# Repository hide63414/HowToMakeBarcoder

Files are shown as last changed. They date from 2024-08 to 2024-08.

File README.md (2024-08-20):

# Barcoderの作り方
## 概要
バーコードリーダーをバーコーダーに改造する方法 [バーコーダー](https://www.electronicosfantasticos.com/works/barcoder/)<br>

## 部品
* バーコードリーダー　[BEVA バーコードリーダー](https://www.amazon.co.jp/BEVA-%E3%83%90%E3%83%BC%E3%82%B3%E3%83%BC%E3%83%89%E3%83%AA%E3%83%BC%E3%83%80%E3%83%BC-%E3%83%90%E3%83%BC%E3%82%B3%E3%83%BC%E3%83%89%E3%82%B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)<br>
他の機種でも可　例えば [Tera バーコードリーダー](https://www.amazon.co.jp/gp/product/B081W1VBHJ/ref=ppx_yo_dt_b_asin_title_o08_s00?ie=UTF8&th=1)<br>
⇒レーザー光学式（ミラーでスキャンするタイプ）で、走査速度が25Hz程度の低速のもの　

* アンプ　[HT82V73A](https://akizukidenshi.com/catalog/g/gI-17849/)
* スピーカー [マイクロスピーカー](https://akizukidenshi.com/catalog/g/gP-12494/)
* コンデンサ　[0.1μF](https://akizukidenshi.com/catalog/g/gP-17818/)  
* コンデンサ　[1.0μF](https://akizukidenshi.com/catalog/g/gP-07549/)
* オーディオ延長ケーブル　[3.5mmステレオミニ](https://akizukidenshi.com/catalog/g/gC-13084/)
* スライドスイッチ　[スライドスイッチ](https://akizukidenshi.com/catalog/g/gP-15370/)
* スペーサ [樹脂ワッシャー](https://akizukidenshi.com/catalog/g/g115881/)
* バーコーダ用基板<br>
  <details><summary>基板</summary>
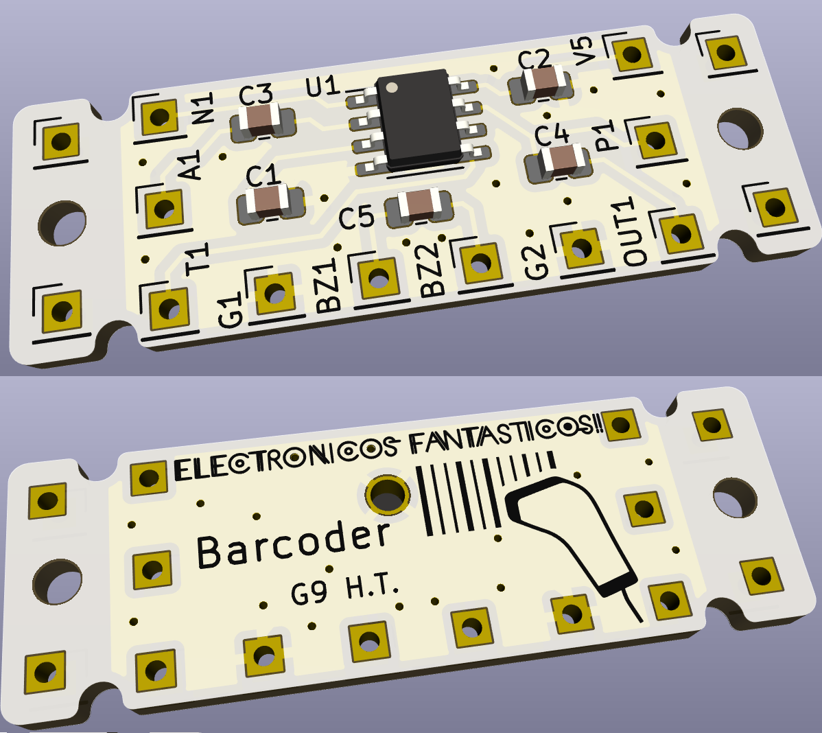
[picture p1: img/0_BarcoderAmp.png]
  </details>

  あるいは
  
  アンプ実装済み基板 [HT82V739使用アンプ基板](https://akizukidenshi.com/catalog/g/g103234/)<br>
  (上記基板使用の際はアンプとコンデンサは不要、配線方法は回路図を参考にしてください。）

## 回路図
<details><summary>回路図</summary>
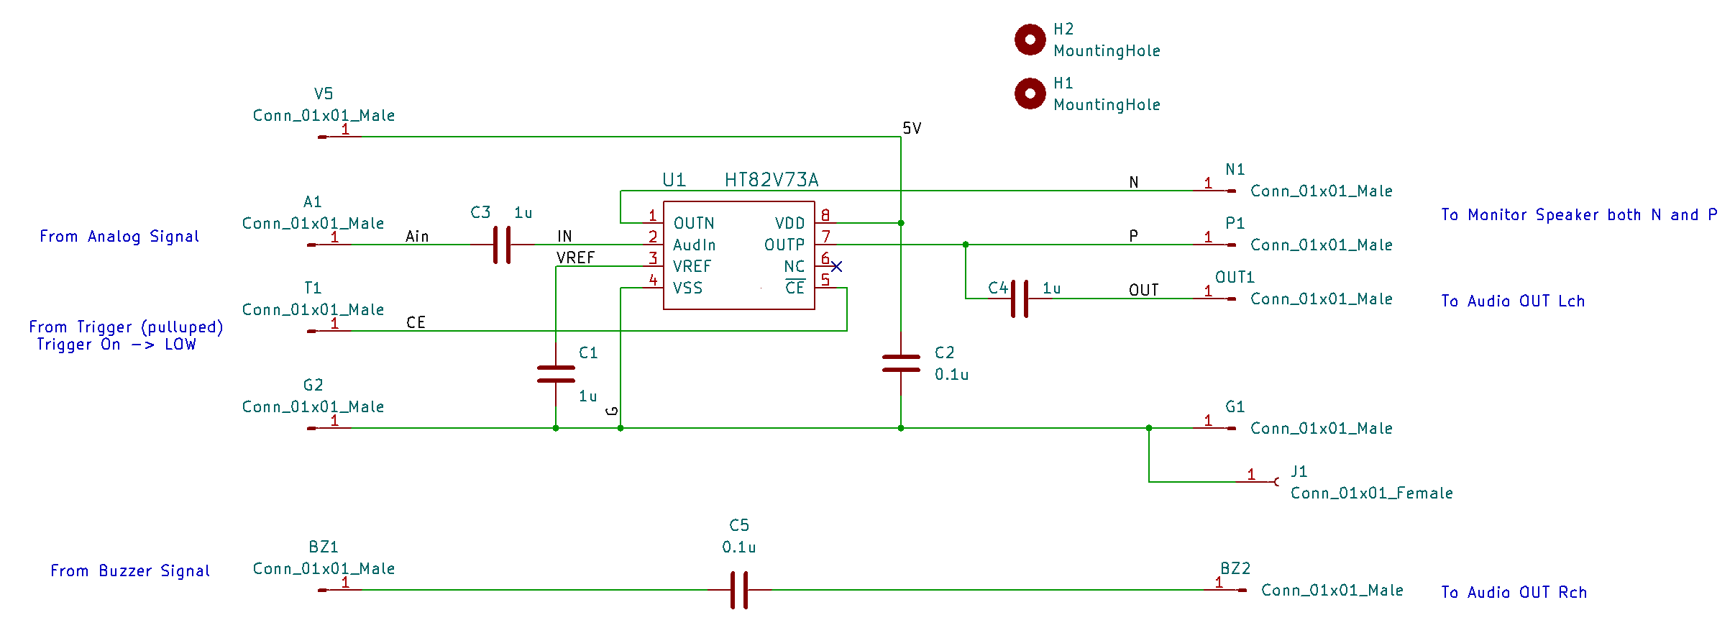
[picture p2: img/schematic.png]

</details>

## 作製手順
0. バーコードリーダーの動作設定
常にレーザーが照射される連続動作モード(Continuous Mode)にするため、設定用のバーコードを読み込む。

1. 配線の準備<br>
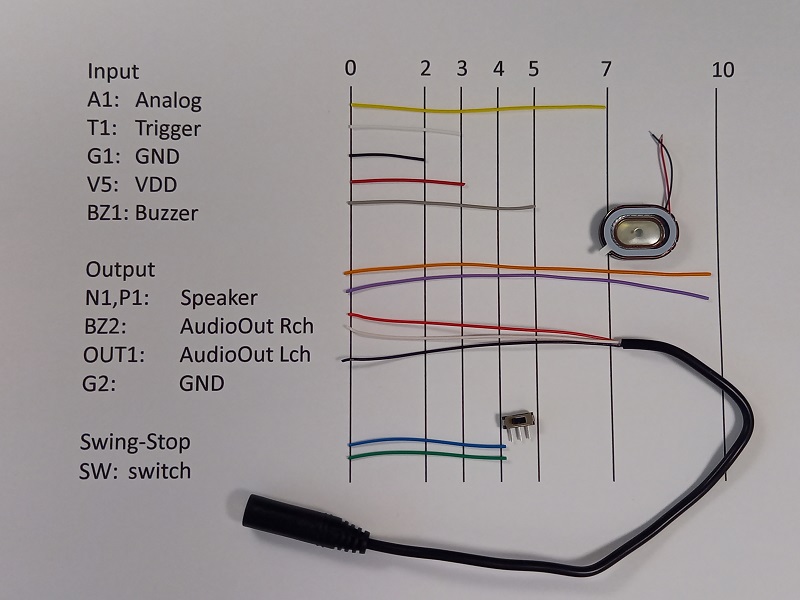
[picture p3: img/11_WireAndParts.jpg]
<br>

1. バーコードリーダ分解<br>
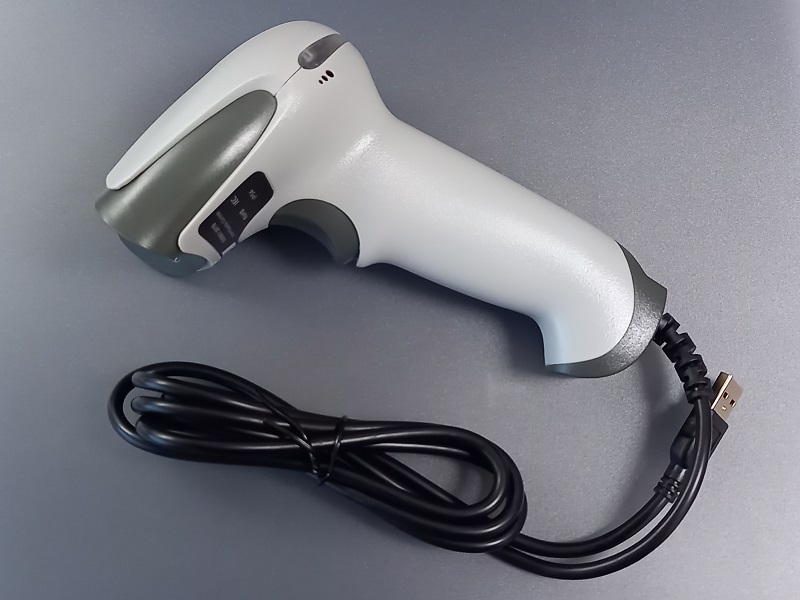
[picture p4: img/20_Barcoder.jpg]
<br>
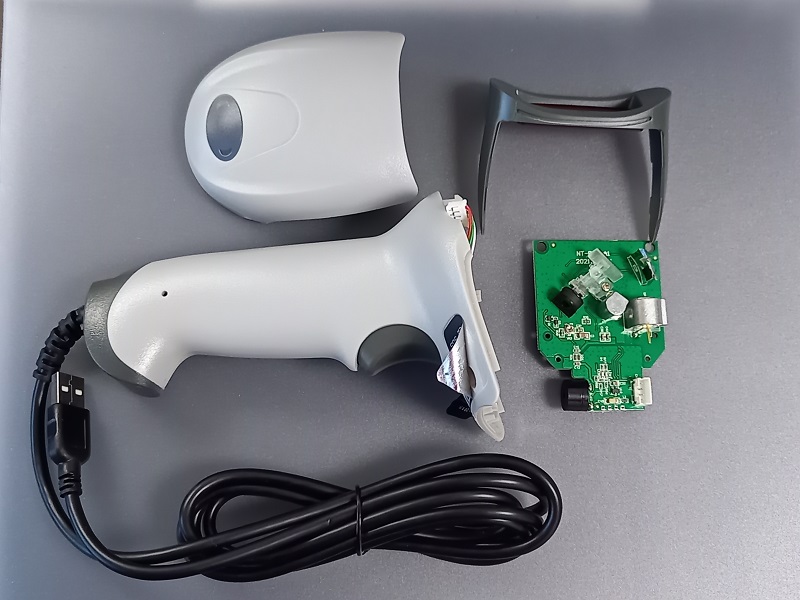
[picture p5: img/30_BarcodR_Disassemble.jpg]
<br>

1. 配線接続<br>
基板裏側シールドを外す<br>
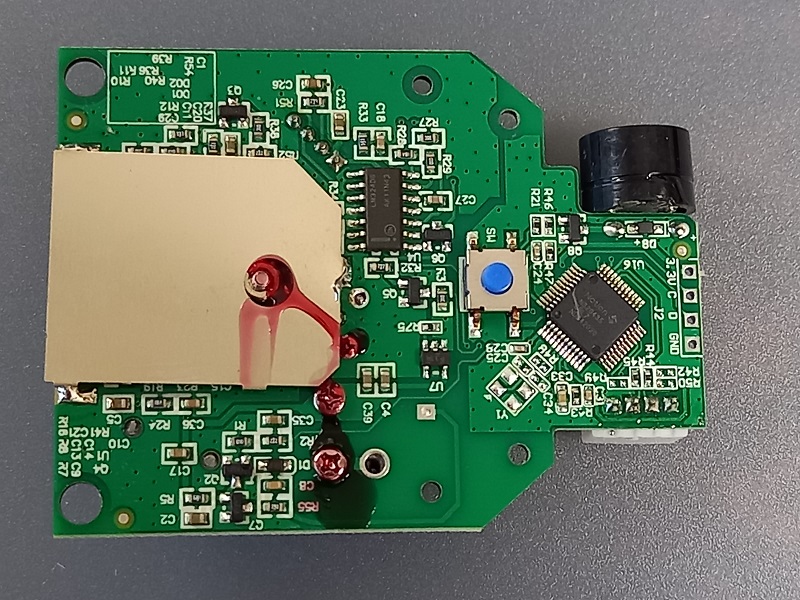
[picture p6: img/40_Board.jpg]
<br>
アナログ(黄)、トリガ(白)、ブザー(灰)、スイング(青・緑)を接続<br>
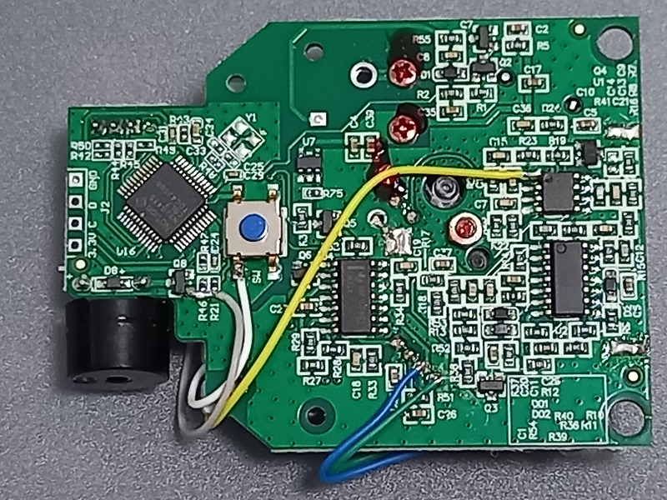
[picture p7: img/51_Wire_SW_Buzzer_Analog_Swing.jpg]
<br>
アナログ(黄) 8pinICの1番ピン<br>
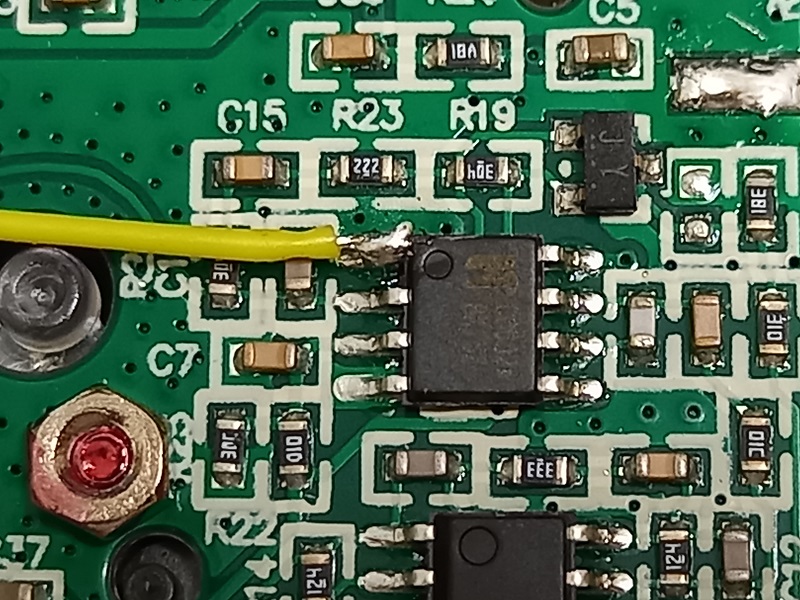
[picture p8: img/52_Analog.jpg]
<br>
トリガ(白)Q8,R46,R21、ブザー(灰)スイッチ足<br>
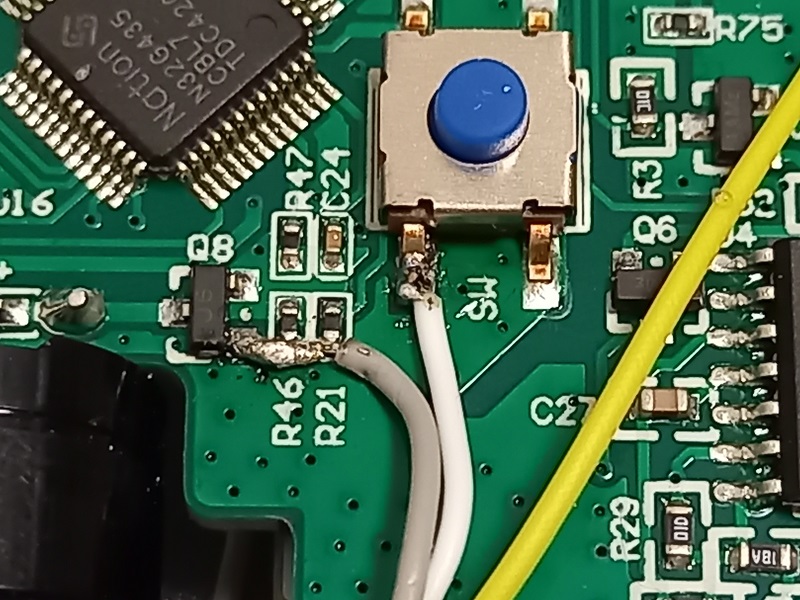
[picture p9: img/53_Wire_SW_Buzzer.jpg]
<br>
スイング(青・緑) コイル端子4本のうち外側2本<br>
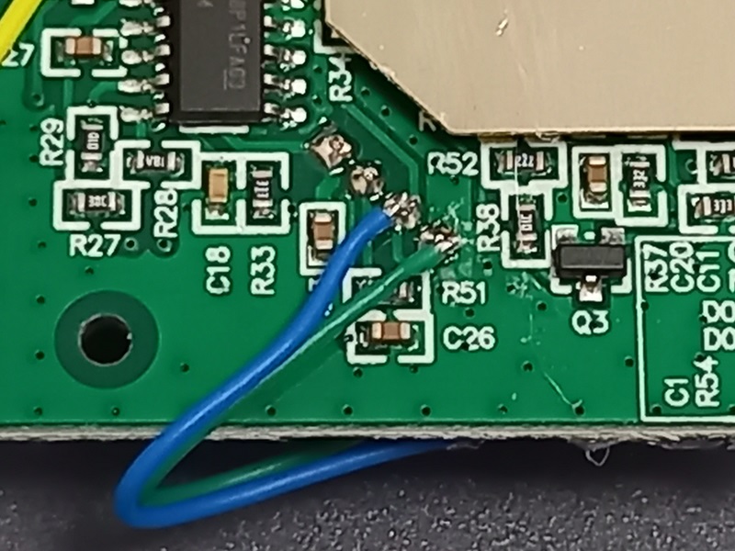
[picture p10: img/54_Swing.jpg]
<br> 

1. 筐体穴あけ(Φ3.2)<br>
AudioOUT用(筐体内に貫通する位置注意)、スピーカー用<br>
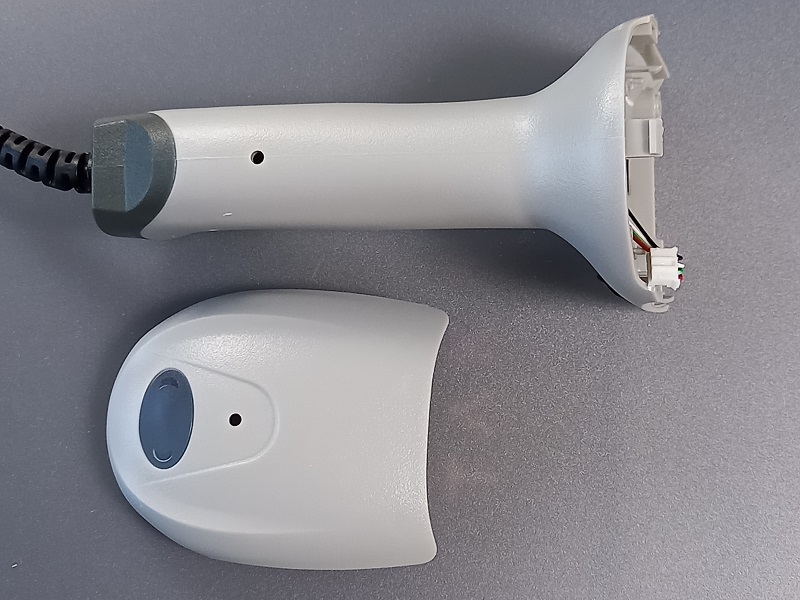
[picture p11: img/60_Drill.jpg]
<br>

1. スピーカ取り付け<br>
スピーカーに配線(橙、紫)取り付け、両面テープで貼る<br>
ホットメルトで固定<br>
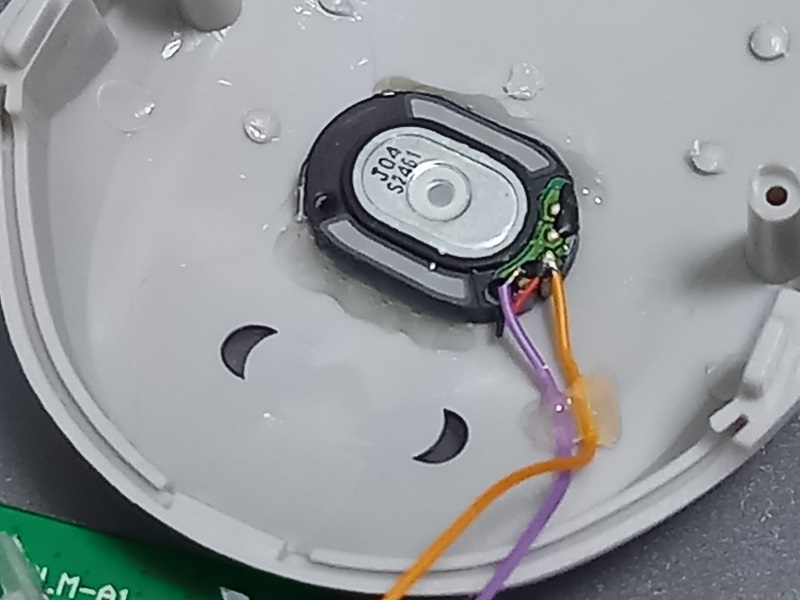
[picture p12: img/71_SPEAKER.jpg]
<br>

1. 基板に部品実装<br>
AMP,C1,C3,C4,C5<br>
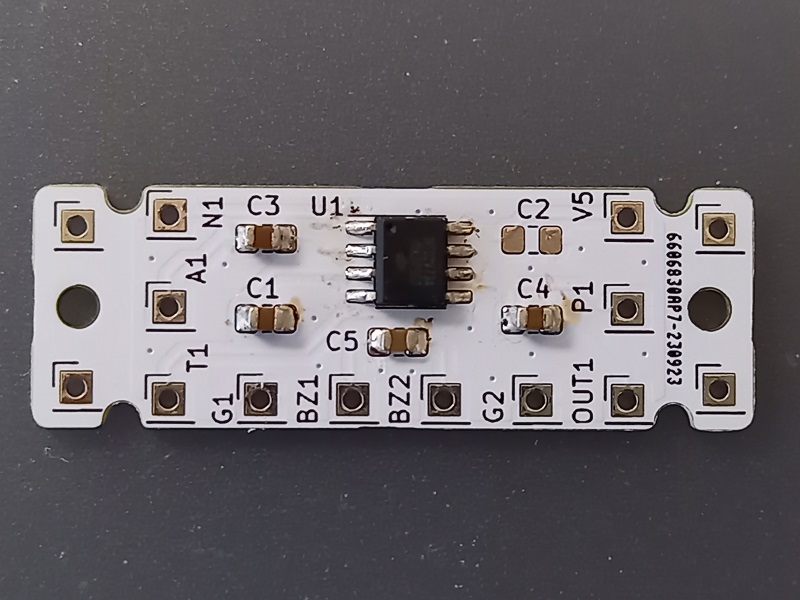
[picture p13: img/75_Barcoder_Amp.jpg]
 <br>

1. 基板に配線接続<br>
GND(黒)G2、5V(赤)V5<br>
アナログ(黄)A1、トリガ(白)T1、ブザー(灰)BZ1<br>
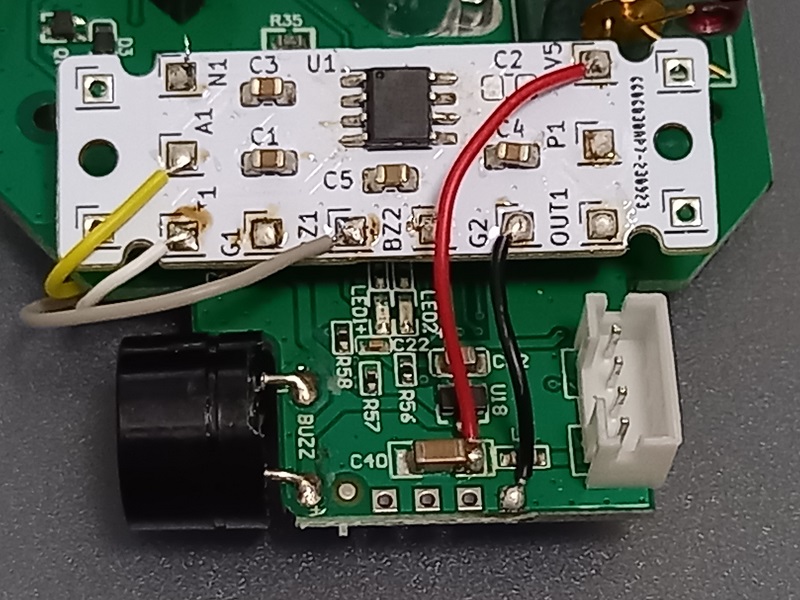
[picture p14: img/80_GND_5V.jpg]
<br>

1. スイング停止用スイッチ取り付け<br>
スイングするミラーに当たらない位置にホットボンドで固定する。<br>
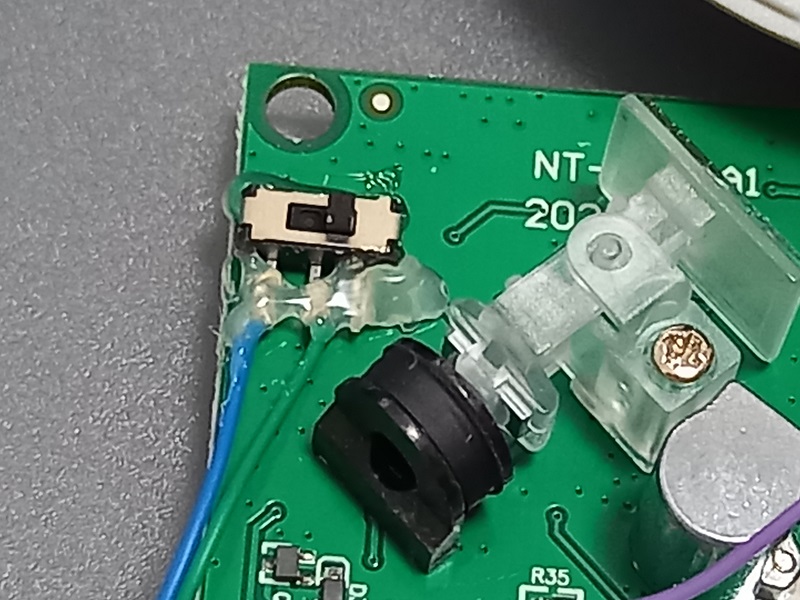
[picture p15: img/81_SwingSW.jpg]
<br>
スイング停止する場合は、スイッチを短絡側に切り替え<br>
ミラーをテープで固定する<br>
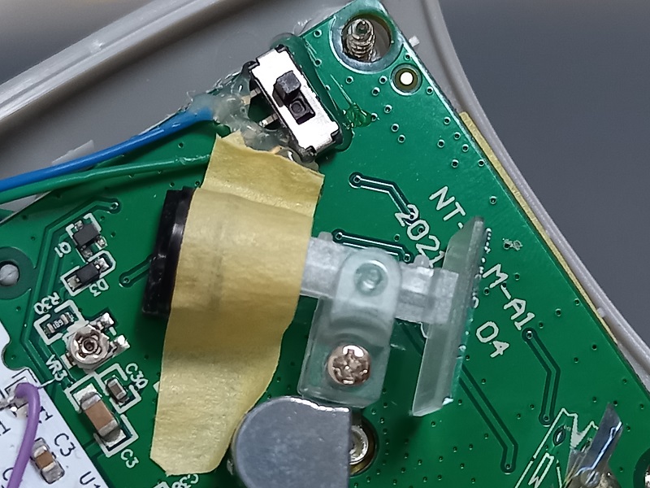
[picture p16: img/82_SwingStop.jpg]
<br>

1. 動作確認<br>
スピーカー(橙、紫)　P1,N1 どちらでもいい<br>
USBコネクタを取り付け<br>
基板反対面のスイッチを押して、ブザーから音が出ればOK<br>
音がでない場合は接続、基板上のICのはんだ付け状況を確認<br>
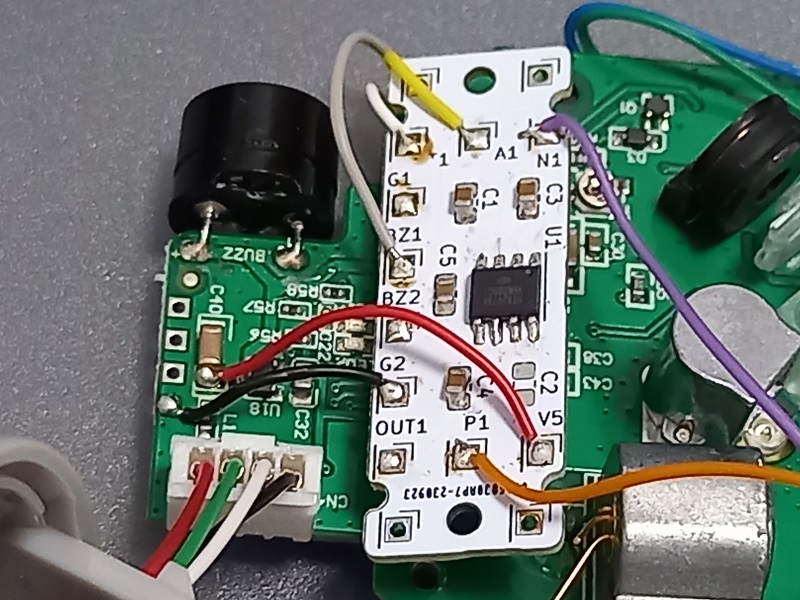
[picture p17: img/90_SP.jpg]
<br>

1. AudioOut接続<br>
AudioOutケーブルを筐体にあけた穴から通して基板に接続する<br>
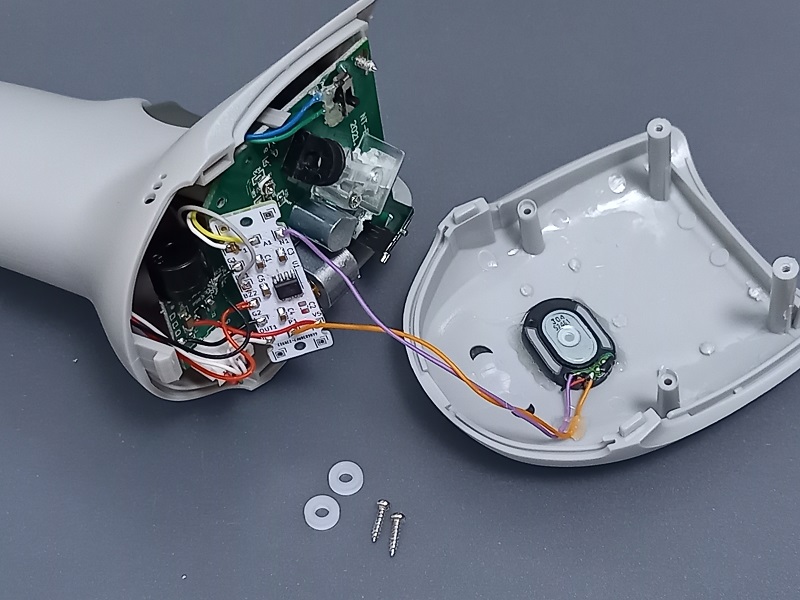
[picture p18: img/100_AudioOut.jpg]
<br>
AudioOut(白)OUT1、AudioOut(赤)BZ2、AudioOut(黒)G1<br>
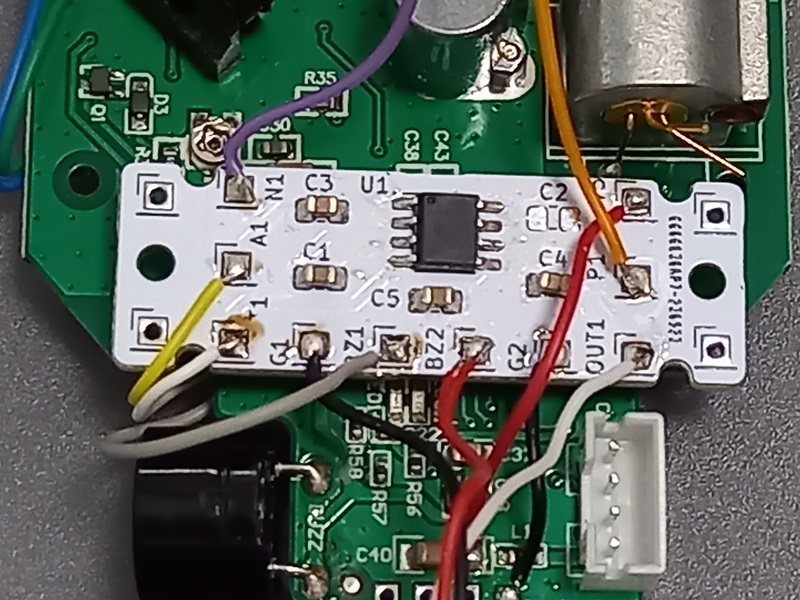
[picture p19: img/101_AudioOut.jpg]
<br>
スペーサを基板の下に入れて固定する<br>
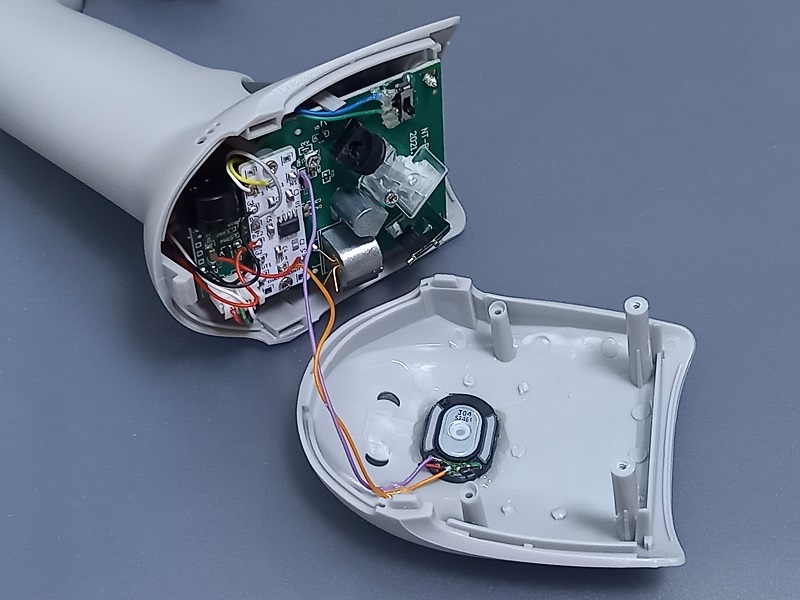
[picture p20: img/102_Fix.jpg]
<br>

1. 動作確認2<br>
トリガボタンが押せるか(ケーブルが挟まっている場合あり)<br>
USBコネクタから給電して縞模様とバーコードを読み込ませる<br>
Lchから縞模様の音がでるか<br>
Rchからバーコード認識音がでるか<br>
（ヘッドホンを接続して確認するとわかりやすい）<br>

1. 組み立て<br>
筐体を元に戻して完成<br>
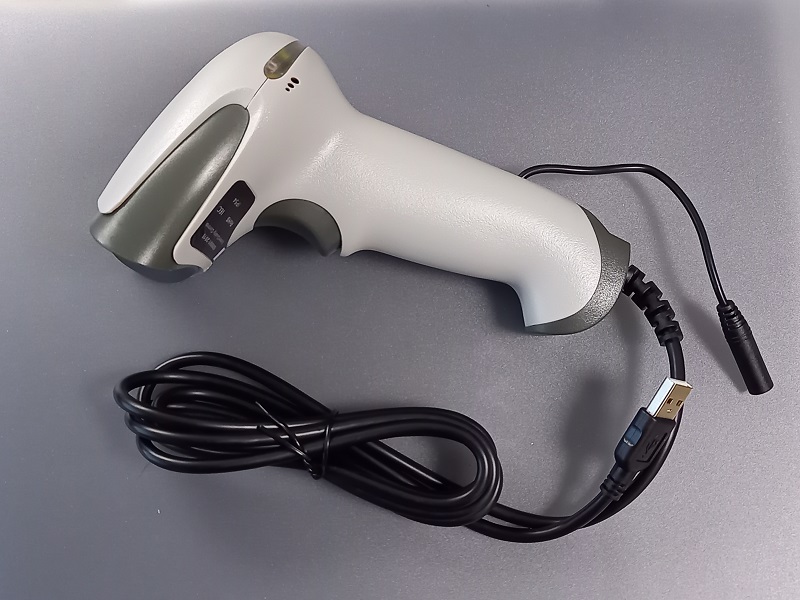
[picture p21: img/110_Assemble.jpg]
<br>

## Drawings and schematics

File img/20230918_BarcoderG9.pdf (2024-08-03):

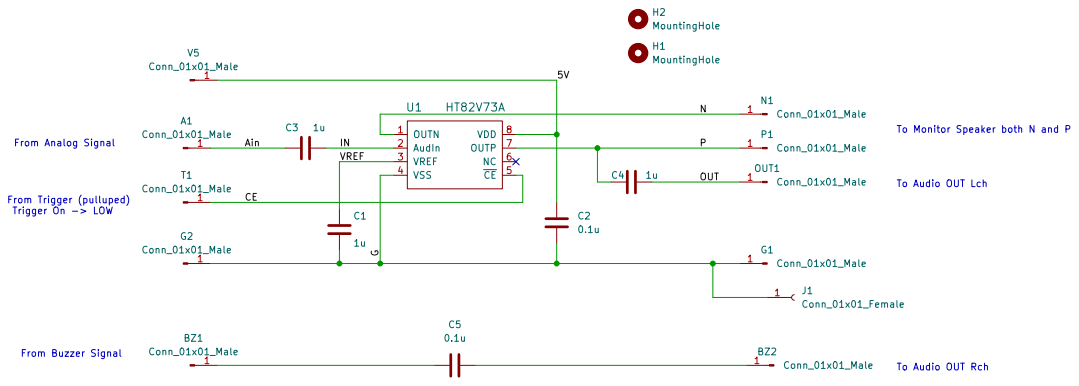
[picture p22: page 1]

To Monitor Speaker both N and P

To Audio OUT Lch To Audio OUT Rch From Buzzer Signal
From Trigger (pulluped)
Trigger On -> LOW

File: 20230918_Barcoder8.kicad_sch Sheet: / ELECTRONICOS FANTASTICOS! 1 G2 Conn_01x01_Male
